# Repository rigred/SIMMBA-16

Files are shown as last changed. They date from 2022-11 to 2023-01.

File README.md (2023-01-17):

# SIMMBA-16. P
Open-source 30 pins 16MB SIMM memory module

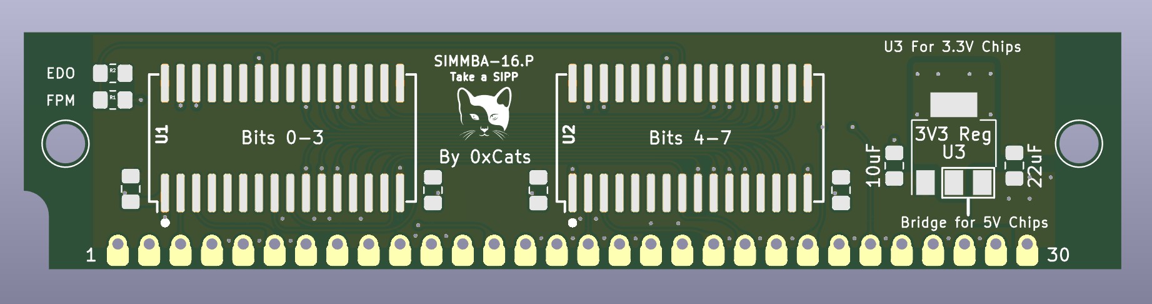
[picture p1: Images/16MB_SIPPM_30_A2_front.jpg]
16MB_SIPPM_30_A2_front


## Status Updates
* 2022-06-12
  * Version 1A assembled and tested [link](https://twitter.com/0xCats/status/1524708654913662977)
* Many months of happily using rev A1 board
* 2022-11-22
  * Version 2A released to the public
* 2023-01-17
  * Added Filthy WIP autorouted Rev. B1 (16MB with Parity) and A11 pullup

# Just gimme the Gerbers!
[gerber.zip](https://raw.githubusercontent.com/rigred/SIMMBA-16/main/production/gerber.zip)

# Ordering specifics:
 * 1.2mm Thickness
 * HASL or ENIG (any finish is fine)

# Why?
Because I have a 486 motherboard that I'm quite fond of that featured a mix of 2x72pin and 4x30pin SIMM sockets.
I wanted to use both at maximum capacity. Also 30 pin SIMM memory prices are not great.

# What is this thing?
A 16MB(the absolute limit) 30 pin SIMM/SIPP Memory module for various PC compatibles.
This board was designed to be as low cost and simple as possible and supports flexibility in ram chip and socket selection.

## Supported RAM chips

3.3V chips may be relatively easily found from cheaply available 256MB EDO DIMM's.

These are by far the preferred choice in comparison to the now rarer 5V chips.

I have tested and validated some of the below chips and found them to be 5V IO tolerant in use despite manufacturer data sheets not directly ascribing such.

Of these the Micron chips are by far the most common and robust. All others have been data sheet checked to be electrically compatible.

## (3.3V)
 * MT4LC16M4H9 (Preferred, Tested & Validated)
 * GM71V65403C (Tested)
 * K4F640412C (Validated)
 * KM44V16104BK (Validated)
## (5V)
 * KM44C16100BK
 * K4E660411C
 * K4F640411B

# Assembly

## Bill of Materials

[HTML BOM](https://htmlpreview.github.io/?https://raw.githubusercontent.com/rigred/SIMMBA-16/main/bom/ibom.html)

## RAM Salvaging
If you are not using new-old-stock chips and are instead salvaging compatible chips form DRAM Modules then I recommend you take the utmost care in desoldering such.
* If possible test your source RAM boards before salvaging, you do not want to be taking risks with unknown quality chips.
* It is very easy to overheat and destroy these old DRAM chips, use a preheater and hot air station or temperature controlled reflow oven to remove the chips
* If you have not done this before, expect mysery pain and failure, but don't give up.
* I bear absolutely no responsibility for any of this should it go horribly wrong.

## Voltage selection
* When 3.3V chips are used it is required to install a suitable 3.3V LDO regulator such as the common AMS1117-3.3 as well as the 10uF Capacitor
* When 5V chips are used you must bridge the indicated pads with a 0-Ohm resistor or suitable piece of metal and install the 22uF Capacitor
* _DO NOT_ install the 3.3V Regulator when using 5V chips and bridging the indicated pads.

## EDO / FPM selection
For the most part only the FPM bridge should be populated. In this mode the CAS signal is tied to the Output Enable signal pin of the chips.
On EDO DRAM chips this forces the output buffers to become invalid and cleared as soon as the CAS is toggled and allows EDO chips to behave like FPM chips.
In rare cases you may want to configure this module as EDO mode, such as in use with 72pin to 4x30pin SIMM-Saver/SIMM-Expander boards.

## SIPP mode
If you wish to use these as SIPP modules, in case say your SIMM sockets are broken, or you've found some very obscure motherboard that both supports SIPP memory and this size of module. Then you can simply solder a right angle 100mil/2.54mm header to the holes along the edge.

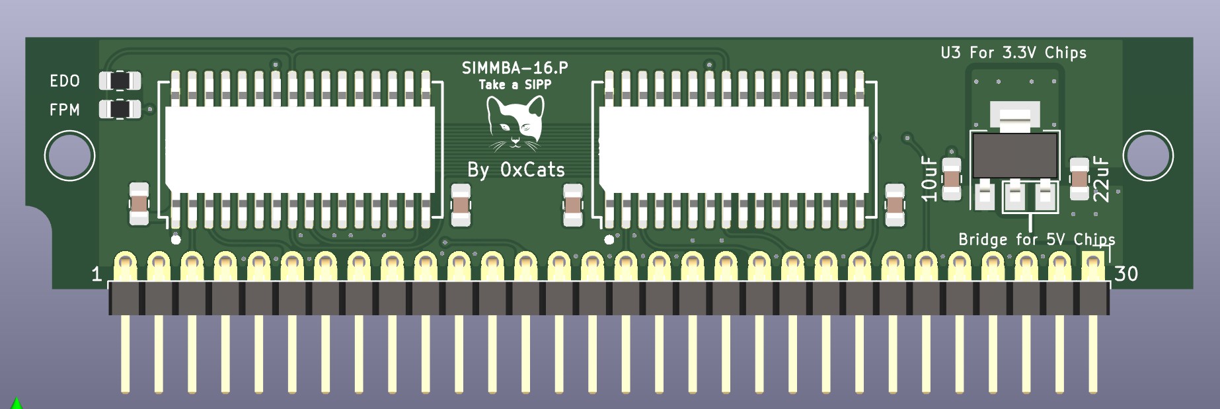
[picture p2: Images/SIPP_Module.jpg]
SIPP_Module


# Soldering
* For repeatable good results when soldering the ram chips in place it is recommended to use a stencil and soldering paste and soldering the whole board in one pass on a hot plate.
* Hand soldering is possible but great care must be taken to ensure good contact on the pads and no solder bridging. *Large quantities of flux recommended.*

# Troubleshooting

1) If you are using the 3.3V regulator design and are experiencing voltage instability it may be necessary to adjust the capacitance of the 5V input and 3.3V output filter capacitors.
  * In this design, less can often be better.

2) After assembly it is recommended to first power test and check your handiwork in expectation of failure. Feel for any hot parts on the DRAM

3) If you are getting memory errors there is a good chance that either some pins are not making good contact or you've overheated one of the chips.

4) Mixing and matching these modules with other modules in the same bank is _NOT_ supported nor recommended.

# Revision A1 testing

The A1 revision SIMMBA module assembled

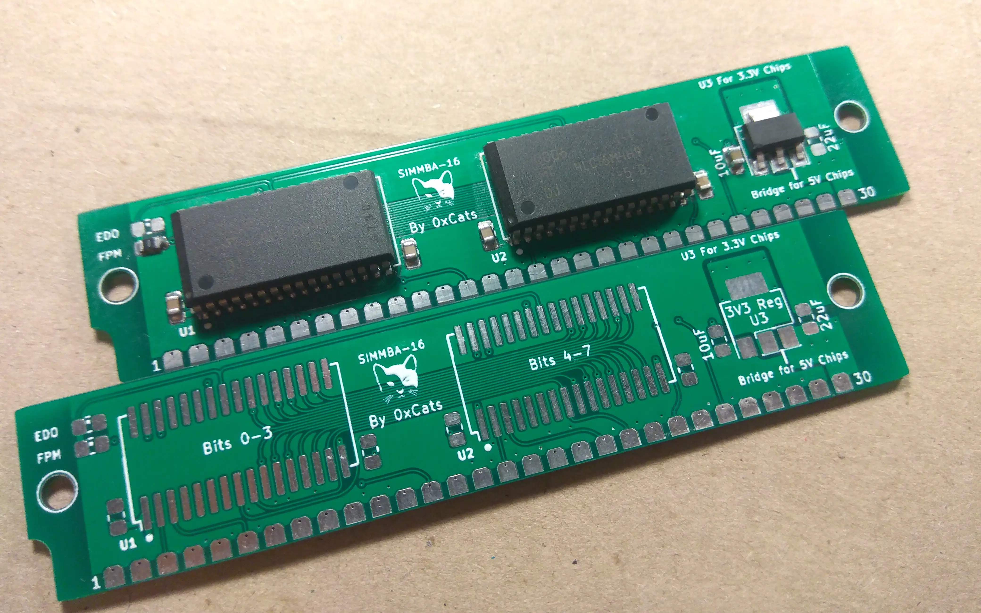
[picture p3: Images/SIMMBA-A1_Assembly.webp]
SIMMBA-A1_Assembly


64MB of SIMMBA A1 revision under test

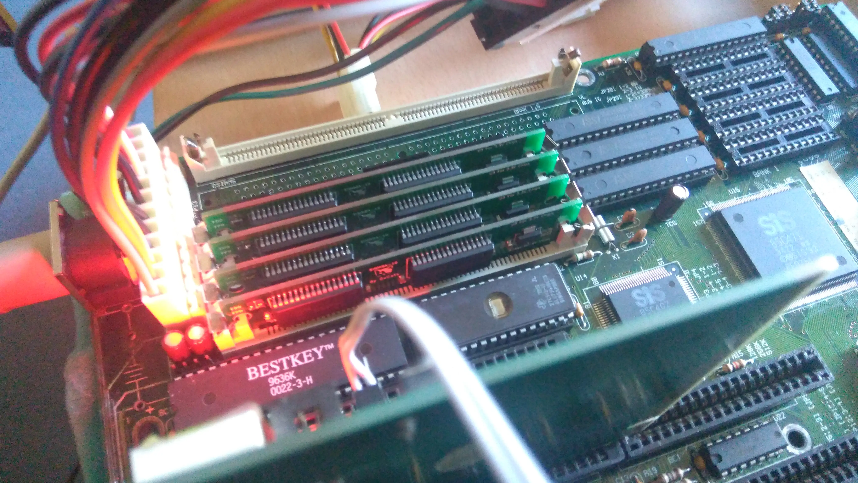
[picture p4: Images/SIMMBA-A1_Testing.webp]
SIMMBA-A1_Testing


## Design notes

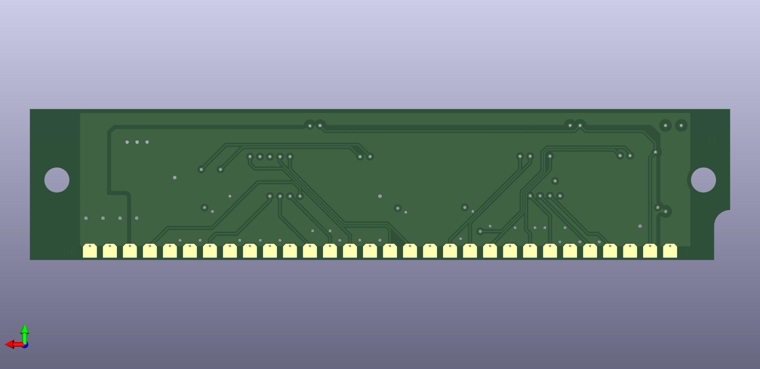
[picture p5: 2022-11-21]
Images/16MB_SIMM_30_A1_back.jpg

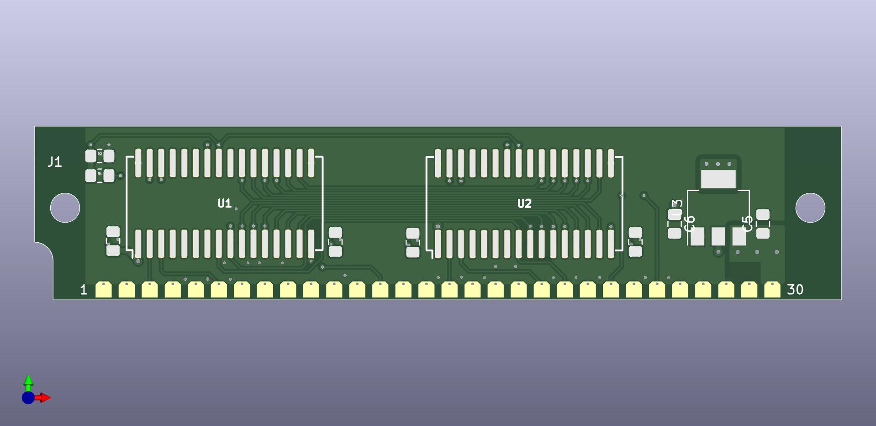
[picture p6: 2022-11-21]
Images/16MB_SIMM_30_A1_front.jpg

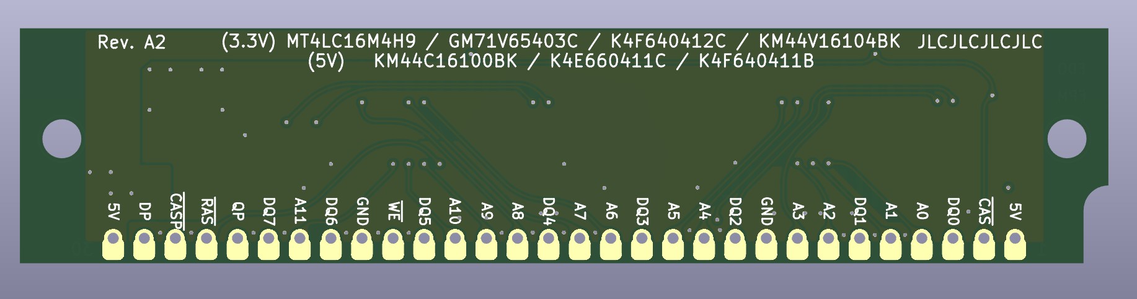
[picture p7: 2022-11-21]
Images/16MB_SIPPM_30_A2_back.jpg

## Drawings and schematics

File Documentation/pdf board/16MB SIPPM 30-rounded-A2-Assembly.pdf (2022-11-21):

1 | 2 | 3 | 4

A

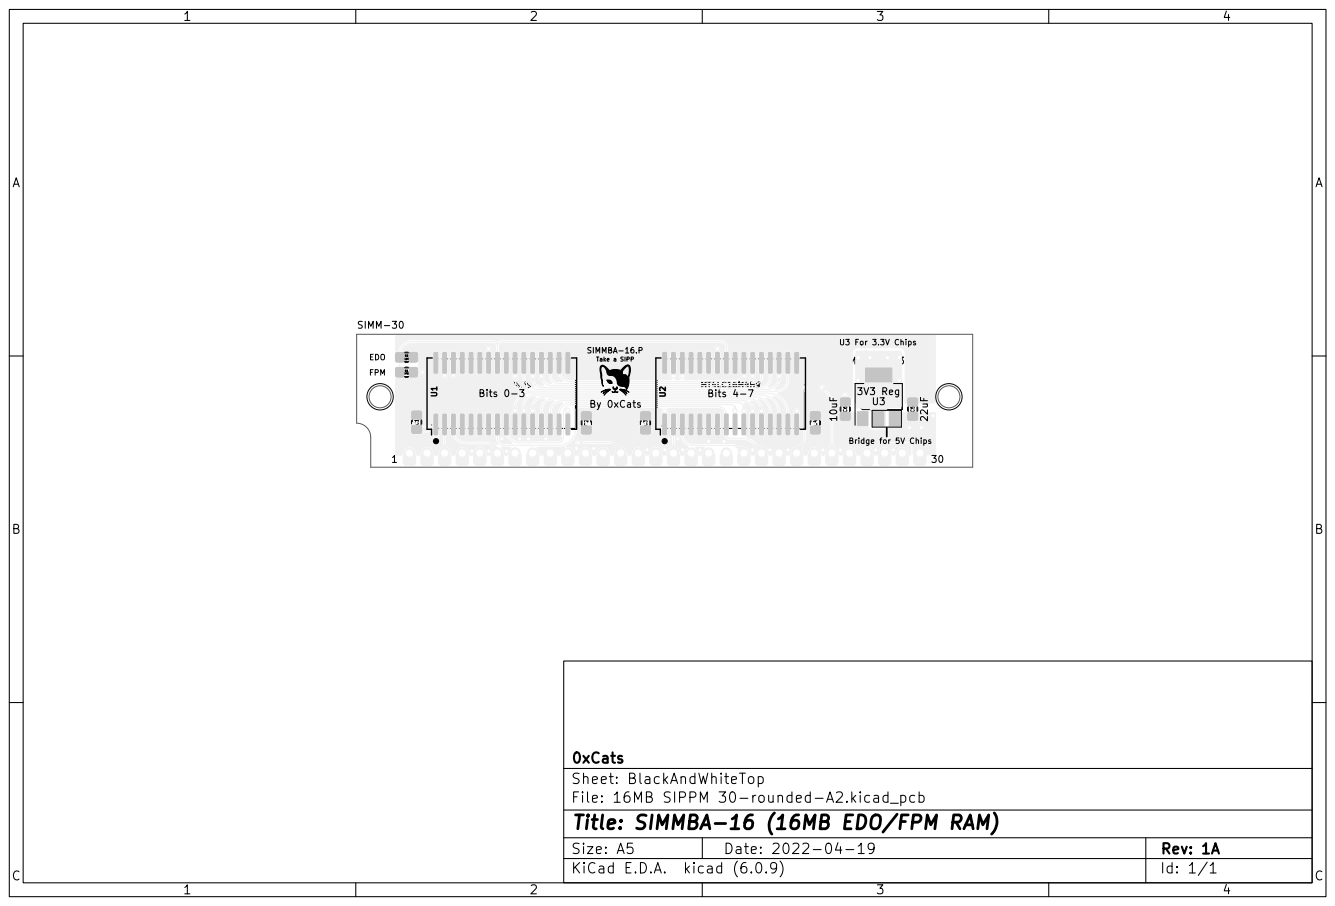
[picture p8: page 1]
BC Date: 2022-04-19 KiCad E.D.A. kicad (6.0.9) Size: A5; Rev: 1A; 0xCats U¹; EDO SIMM-30; FPM; C⁵ AMS1117-3.3 U3 EDO; 3V3 Reg; SIMMBA-16.P; Bridge for 5V Chips FPM; Bits 0-3; Take a SIPP; Bits 4-7 By 0xCats; U3 For 3.3V Chips U¹; 22uFU3

Sheet: BlackAndWhiteTop
File: 16MB SIPPM 30-rounded-A2.kicad_pcb
Id: 1/1 Title: SIMMBA-16 (16MB EDO/FPM RAM)

1 | 2 | 3 | 4

A

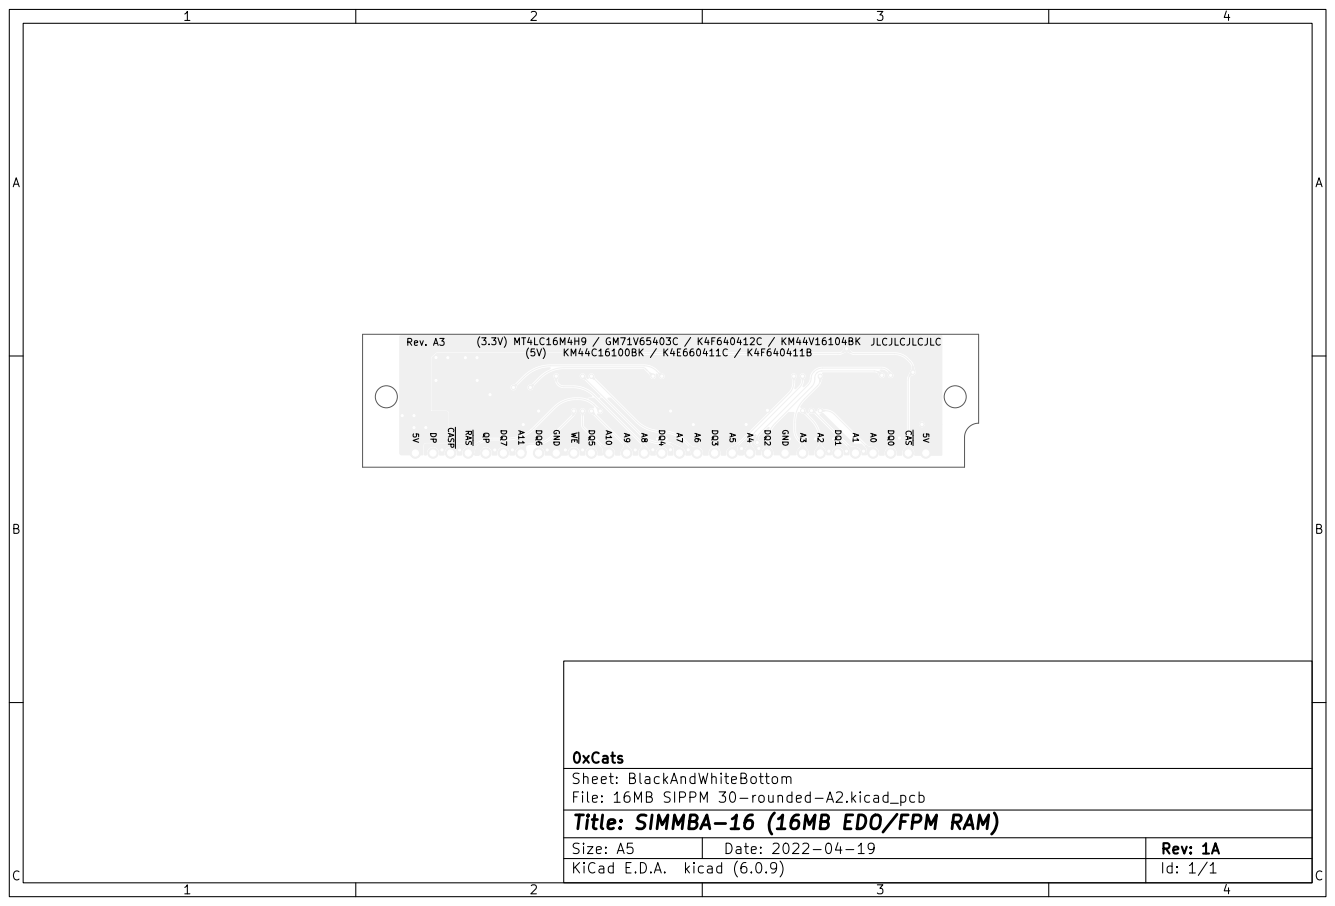
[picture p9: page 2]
BC Date: 2022-04-19 KiCad E.D.A. kicad (6.0.9) Size: A5; Rev: 1A; 0xCats ~{RAS}; JLCJLCJLCJLC DQ4; GND; 5V Rev. A3; ~{CAS} DQ7; DQ1 A9 ~{CASP}

File: 16MB SIPPM 30-rounded-A2.kicad_pcb Sheet: BlackAndWhiteBottom
Id: 1/1 Title: SIMMBA-16 (16MB EDO/FPM RAM)

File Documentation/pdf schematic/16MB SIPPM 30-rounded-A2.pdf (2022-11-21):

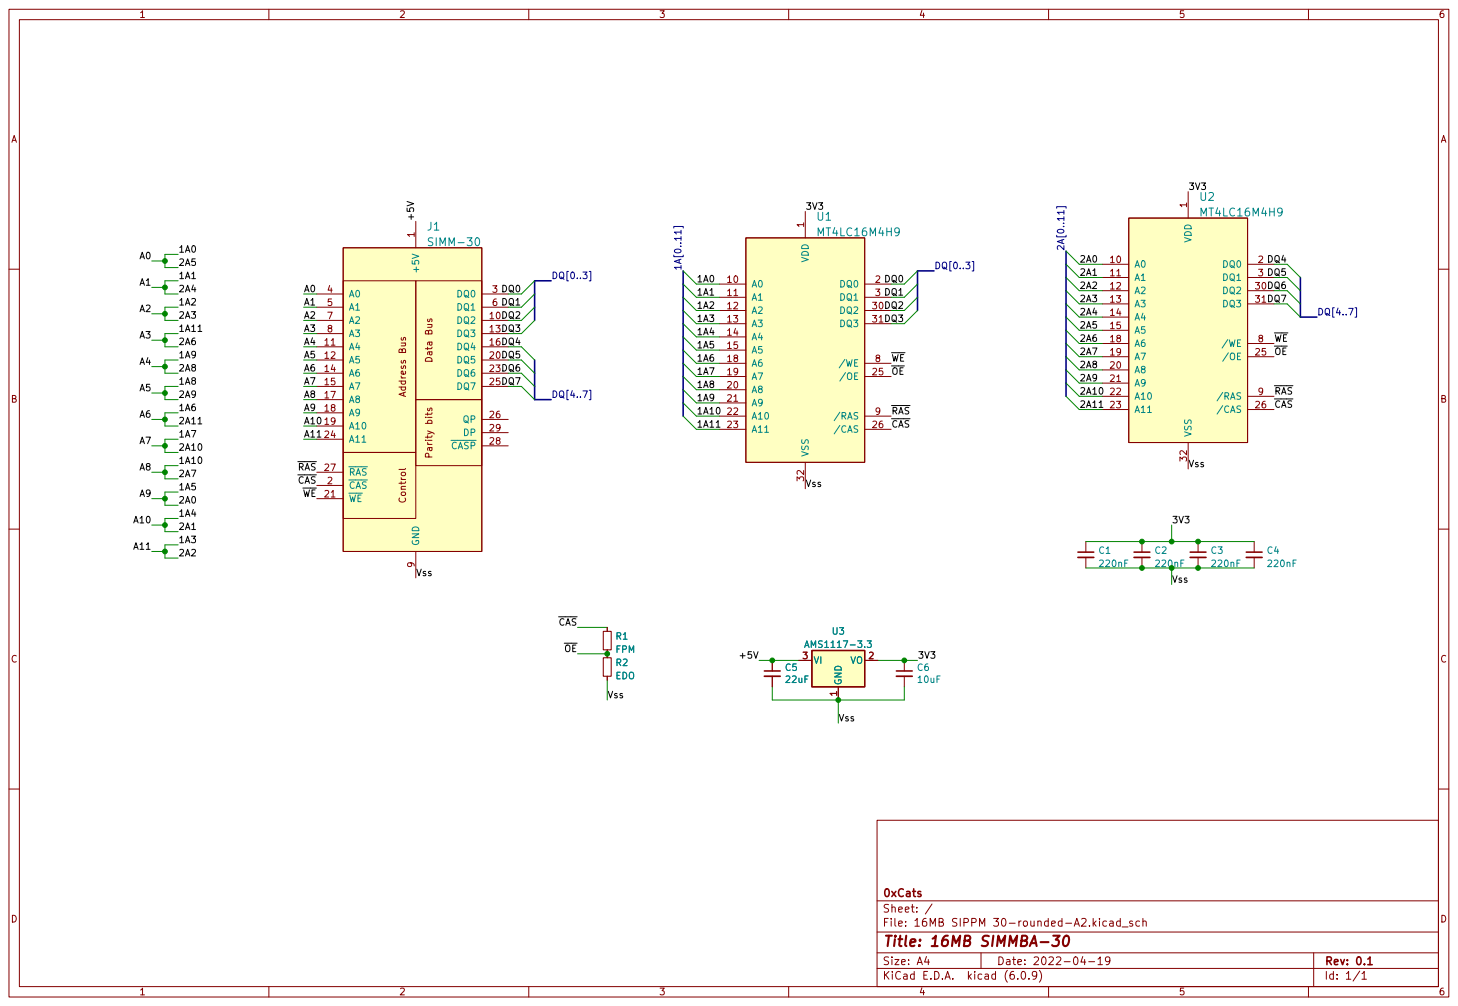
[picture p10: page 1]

1 VO 2 VI 3 U3 AMS1117-3.3 R1 FPM VDD

1 DQ2 10 A4 11 A5 12 DQ3 13 A6 14 A7 15 DQ4 16 A8 17 A9 18 A10 19 ~{CAS} 2 DQ5 20 ~{WE} 21 DQ6 23 A11 24 DQ7 25 QP 26 ~{RAS} 27 ~{CASP} 28 DP 29 DQ0 3 A0 4 A1 5 DQ1 6 A2 7 A3 8 GND

File: 16MB SIPPM 30-rounded-A2.kicad_sch Sheet: / 0xCats GND

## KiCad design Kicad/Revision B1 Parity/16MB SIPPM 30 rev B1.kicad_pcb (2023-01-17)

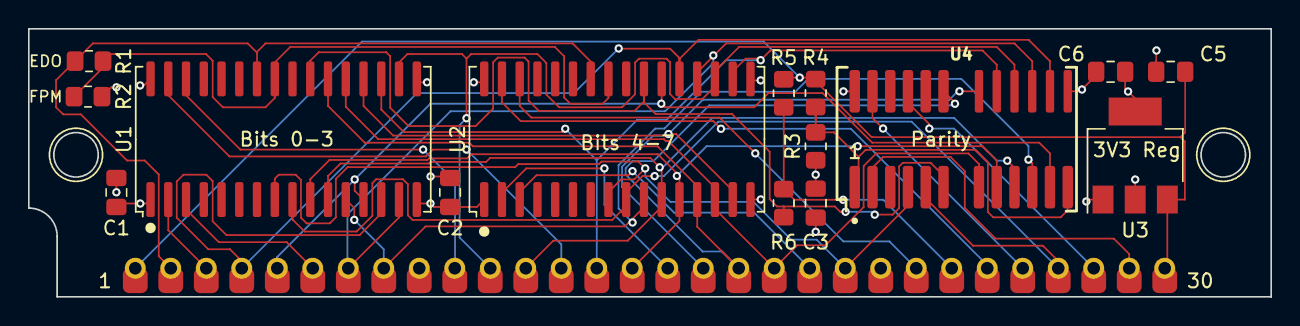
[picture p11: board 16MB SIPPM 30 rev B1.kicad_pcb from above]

Board: 4 copper layers, 88.9 x 19.2 mm, 16 parts (0 on the bottom side), 32 nets.

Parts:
C1, C2, C3: 220nF; C_0805_2012Metric_Pad1.18x1.45mm_HandSolder
C5: 22uF; C_0805_2012Metric_Pad1.18x1.45mm_HandSolder
C6: 10uF; C_0805_2012Metric_Pad1.18x1.45mm_HandSolder
J1: SIMM-30; SIPP_30_A2
R1: FPM; R_0805_2012Metric_Pad1.20x1.40mm_HandSolder
R2: EDO; R_0805_2012Metric_Pad1.20x1.40mm_HandSolder
R3, R4, R6: 0; R_0805_2012Metric_Pad1.20x1.40mm_HandSolder
R5: 10K; R_0805_2012Metric_Pad1.20x1.40mm_HandSolder
U1, U2: MT4LC16M4H9; SOJ-32_10.16x21.50mm_P1.27mm
U3: AMS1117-3.3; SOT-223-3_TabPin2
U4: HM5116100S; SOJ-26_300mil

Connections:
+3V3: C1.1, C2.1, C3.1, C6.1, R3.1, U1.1 (VDD), U1.16 (VDD), U2.1 (VDD), U2.16 (VDD), U3.2 (VO)
+5V: C5.1, J1.1 (+5V), J1.30 (+5V), R4.2, R5.1, U3.3 (VI)
/2A0: J1.8 (A3), U1.12 (A2), U2.10 (A0), U4.11 (A2)
/2A1: J1.12 (A5), U1.11 (A1), U2.11 (A1), U4.10 (A1)
/2A2: J1.15 (A7), U1.10 (A0), U2.12 (A2), U4.9 (A0)
/2A3: J1.18 (A9), U1.22 (A10), U2.13 (A3), U4.21 (A9)
/2A4: J1.19 (A10), U1.21 (A9), U2.14 (A4), U4.8 (A10)
/2A5: J1.17 (A8), U1.20 (A8), U2.15 (A5), U4.19 (A8)
/2A6: J1.14 (A6), U1.19 (A7), U2.18 (A6), U4.18 (A7)
/2A7: J1.11 (A4), U1.18 (A6), U2.19 (A7), U4.17 (A6)
/2A8: J1.7 (A2), U1.15 (A5), U2.20 (A8), U4.16 (A5)
/2A9: J1.4 (A0), U1.14 (A4), U2.21 (A9), U4.15 (A4)
/2A10: J1.5 (A1), U1.13 (A3), U2.22 (A10), U4.12 (A3)
/2A11: R6.2, U1.23 (A11), U2.23 (A11), U4.6 (A11)
/DP: J1.29 (DP_IN), U4.2 (DIN)
/DQ0: J1.3 (DQ0), U1.2 (DQ0)
/DQ1: J1.6 (DQ1), U1.3 (DQ1)
/DQ2: J1.10 (DQ2), U1.30 (DQ2)
/DQ3: J1.13 (DQ3), U1.31 (DQ3)
/DQ4: J1.16 (DQ4), U2.2 (DQ0)
/DQ5: J1.20 (DQ5), U2.3 (DQ1)
/DQ6: J1.23 (DQ6), U2.30 (DQ2)
/DQ7: J1.25 (DQ7), U2.31 (DQ3)
/QP: J1.26 (DP_OUT), U4.25 (DOUT)
/SIMM_A11: J1.24 (A11), R5.2, R6.1
/VDD_PAR: R3.2, R4.1, U4.1 (+5V), U4.13 (+5V)
/~CASP: J1.28 (~CASP), U4.23 (/CAS)
/~CAS: J1.2 (~CAS), R1.1, U1.26 (/CAS), U2.26 (/CAS)
/~OE: R1.2, R2.1, U1.25 (/OE), U2.25 (/OE)
/~RAS: J1.27 (~RAS), U1.9 (/RAS), U2.9 (/RAS), U4.5 (/RAS)
/~WE: J1.21 (~WE), U1.8 (/WE), U2.8 (/WE), U4.4 (/WE)
GND: C1.2, C2.2, C3.2, C5.2, C6.2, J1.9 (GND), J1.22 (GND), R2.2, U1.17 (VSS), U1.32 (VSS), U2.17 (VSS), U2.32 (VSS), U3.1 (GND), U4.14 (VSS), U4.26 (VSS)

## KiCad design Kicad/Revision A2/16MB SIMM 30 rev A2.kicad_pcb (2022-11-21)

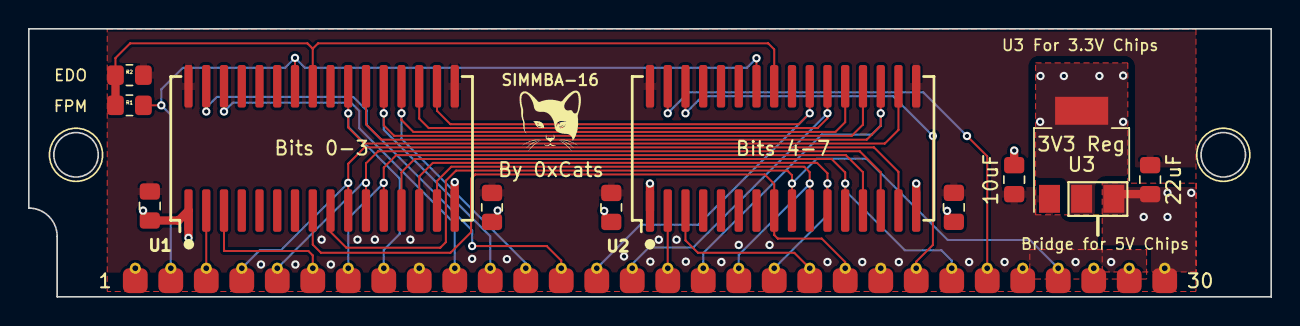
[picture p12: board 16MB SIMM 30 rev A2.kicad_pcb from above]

Board: 2 copper layers, 88.9 x 19.2 mm, 12 parts (0 on the bottom side), 27 nets.

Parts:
C1, C2, C3, C4: 220nF; C_0805_2012Metric_Pad1.18x1.45mm_HandSolder
C5: 22uF; C_0805_2012Metric_Pad1.18x1.45mm_HandSolder
C6: 10uF; C_0805_2012Metric_Pad1.18x1.45mm_HandSolder
J1: SIMM-30; SIMM_30_A2
R1: FPM; R_0805_2012Metric_Pad1.20x1.40mm_HandSolder
R2: EDO; R_0805_2012Metric_Pad1.20x1.40mm_HandSolder
U1, U2: MT4LC16M4H9; SOJ-32_400mil
U3: AMS1117-3.3; SOT-223-3_TabPin2

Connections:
+5V: C5.1, J1.1 (+5V), J1.30 (+5V), U3.3 (VI)
/2A0: J1.18 (A9), U1.15 (A5), U2.10 (A0)
/2A1: J1.19 (A10), U1.14 (A4), U2.11 (A1)
/2A2: J1.24 (A11), U1.13 (A3), U2.12 (A2)
/2A3: J1.7 (A2), U1.12 (A2), U2.13 (A3)
/2A4: J1.5 (A1), U1.11 (A1), U2.14 (A4)
/2A5: J1.4 (A0), U1.10 (A0), U2.15 (A5)
/2A6: J1.8 (A3), U1.23 (A11), U2.18 (A6)
/2A7: J1.17 (A8), U1.22 (A10), U2.19 (A7)
/2A8: J1.11 (A4), U1.21 (A9), U2.20 (A8)
/2A9: J1.12 (A5), U1.20 (A8), U2.21 (A9)
/2A10: J1.15 (A7), U1.19 (A7), U2.22 (A10)
/2A11: J1.14 (A6), U1.18 (A6), U2.23 (A11)
/DQ0: J1.3 (DQ0), U1.2 (DQ0)
/DQ1: J1.6 (DQ1), U1.3 (DQ1)
/DQ2: J1.10 (DQ2), U1.30 (DQ2)
/DQ3: J1.13 (DQ3), U1.31 (DQ3)
/DQ4: J1.16 (DQ4), U2.2 (DQ0)
/DQ5: J1.20 (DQ5), U2.3 (DQ1)
/DQ6: J1.23 (DQ6), U2.30 (DQ2)
/DQ7: J1.25 (DQ7), U2.31 (DQ3)
/~CAS: J1.2 (~CAS), R1.1, U1.26 (/CAS), U2.26 (/CAS)
/~OE: R1.2, R2.1, U1.25 (/OE), U2.25 (/OE)
/~RAS: J1.27 (~RAS), U1.9 (/RAS), U2.9 (/RAS)
/~WE: J1.21 (~WE), U1.8 (/WE), U2.8 (/WE)
GND: C1.2, C2.2, C3.2, C4.2, C5.2, C6.2, J1.9 (GND), J1.22 (GND), R2.2, U1.17 (VSS), U1.32 (VSS), U2.17 (VSS), U2.32 (VSS), U3.1 (GND)
VDD: C1.1, C2.1, C3.1, C4.1, C6.1, U1.1 (VDD), U1.16 (VDD), U2.1 (VDD), U2.16 (VDD), U3.2 (VO)

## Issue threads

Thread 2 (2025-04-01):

add some reister for 3.3v protect.

youxiaojie, 2025-04-01:
I advice to add some resiter for 3.3v protect.

rigred, 2025-04-17:
Hi

Could you explain whay you mean by this? Are you suggesting to add a
current limiting resistor?
Maybe something got lost in translation.

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

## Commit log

2022-11-21 First upload of 16MB SIMMBA rev A2
    [16MB SIMM 30 rev A2.kicad_pcb, 16MB SIMM 30-rounded-A2.kicad_pcb, 16MB SIMM 30-rounded.kicad_pcb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]
2022-11-21 fixed pads missing on back layer
    [16MB SIPPM 30-rounded-A2.kicad_pcb]
2022-11-22 interactive html bom added
2022-11-22 update bom to A2
2022-11-22 remove redundant images
    [16MB SIPPM 30-rounded-A2.kicad_pcb]
2023-01-17 * Adds rough 16MB with parity variant
    Cleaned up Project structure and placed boards into Kicad/<Revisions>
    directories
    [16MB SIMM 30 rev A2.kicad_pcb, 16MB SIMM 30 rev A2.kicad_sch, 16MB SIMM 30-rounded-A2.kicad_pcb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]
2023-01-17 minor Rev B1 cleanups - not prod ready
    [16MB SIPPM 30 rev B1.kicad_pcb, 16MB SIPPM 30 rev B1.kicad_sch]

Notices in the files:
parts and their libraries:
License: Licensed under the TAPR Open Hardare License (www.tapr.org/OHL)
